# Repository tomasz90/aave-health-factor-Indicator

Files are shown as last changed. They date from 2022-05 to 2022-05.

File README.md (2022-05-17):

# Aave Health Factor Indicator


This project shows how healthy is your aave account. It has 16 built in leds as well as buzzer which signals when your hf drops below certain level.
It has a nice logo which shines in AAVE brand colors.

If you want to build this project you need:

* ESP8266 or ESP32
* 3x NEOPIXEL WS2812B modules, in my case I used two pcbs modules + few cm of flexible strips to light up logo
* one 5v buzzer
* few cables
* 3d prints based on attached stl files, one print needs transparent filament
* few insterts
* few screws

Pins needed to connect peripherals(leds, buzzer) are written in code - you can change them if you preffer, doesnt matter.
After programming controller, connect to access point created by ESP8266, configure your SSID and password.




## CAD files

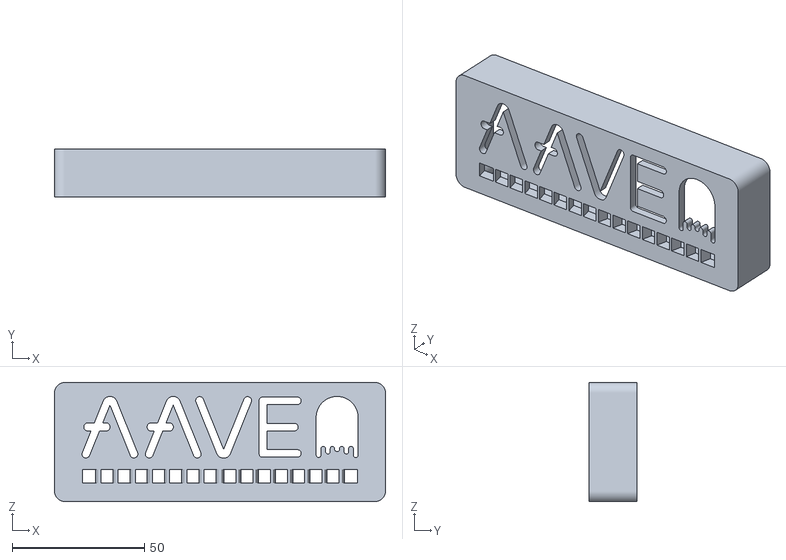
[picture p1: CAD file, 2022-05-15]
stl-3d/aave.stl
125.0 x 18.0 x 45.0

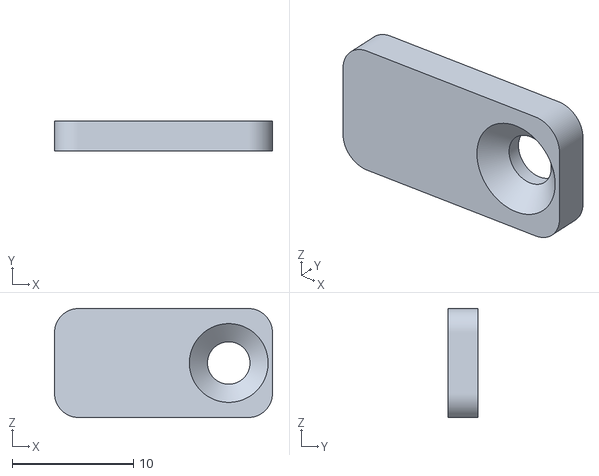
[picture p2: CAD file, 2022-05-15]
stl-3d/esp_holder.stl
18.0 x 2.50 x 9.00

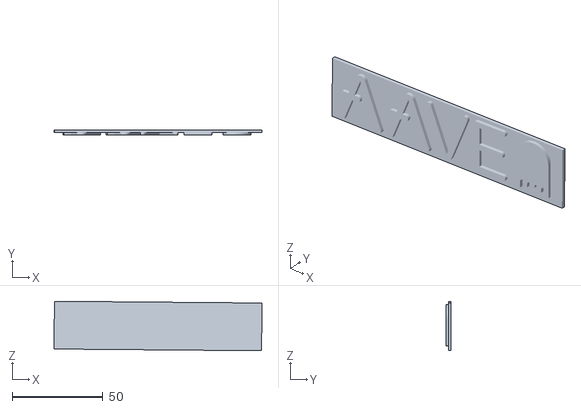
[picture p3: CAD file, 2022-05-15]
stl-3d/aave_window.stl
114.6 x 3.00 x 27.3

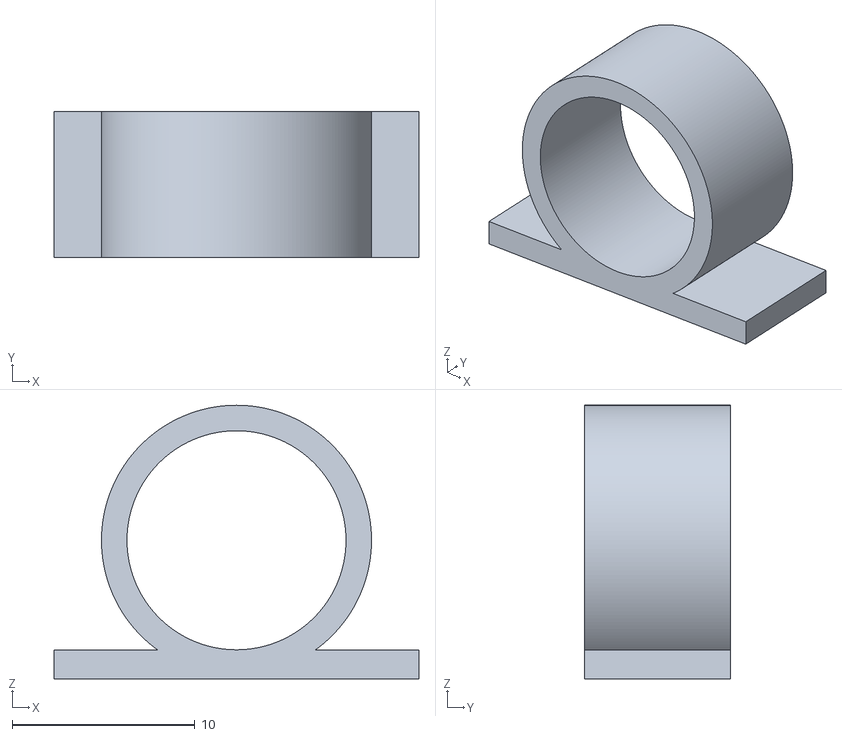
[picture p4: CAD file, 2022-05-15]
stl-3d/aave_speaker_holder.stl
20.0 x 8.00 x 15.0

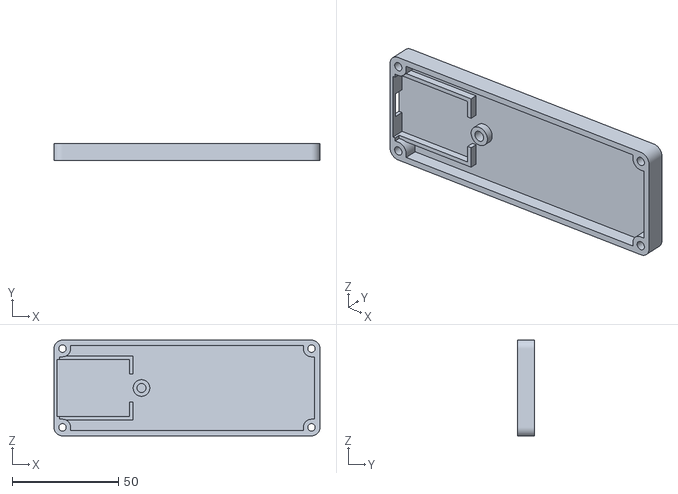
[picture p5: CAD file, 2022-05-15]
stl-3d/aave_cover.stl
125.0 x 8.00 x 45.0

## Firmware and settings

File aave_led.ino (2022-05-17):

#include <ESP8266WiFi.h>
#include <WiFiManager.h>
#include <Adafruit_NeoPixel.h>
#include <bitset>
#include <EEPROM.h>
#include <ESP8266HTTPClient.h>
#include <WiFiClientSecureBearSSL.h>

WiFiServer server(80);
WiFiManager manager;

String header;

struct Color {
  uint8 red;
  uint8 green;
  uint8 blue;
};

struct Settings {
  char chain[15];
  char address[42];
};

Settings settings;

String avaxRpc = "https://api.avax.network/ext/bc/C/rpc";
String polygonRpc = "https://polygon-rpc.com/";

String avaxPool = "0x4f01aed16d97e3ab5ab2b501154dc9bb0f1a5a2c";
String polygonPool = "0x8dFf5E27EA6b7AC08EbFdf9eB090F32ee9a30fcf";

String avaxPoolV3 = "0x794a61358D6845594F94dc1DB02A252b5b4814aD";
String polygonPoolV3 = "0x794a61358D6845594F94dc1DB02A252b5b4814aD";

unsigned long previousMillis = -25000;
const long interval = 30000;

static float hf;

void setup() {

  Serial.begin(9600);
  EEPROM.begin(sizeof(Settings));
  EEPROM.get(0, settings);

  setupAaveColors();
  setupIndicatorColors();

  manager.setConnectTimeout(10);
  manager.setConfigPortalTimeout(120);
  manager.autoConnect("ESP_AAVE", "password");

  connectToWifi();
  server.begin();
}

void loop() {
  displayAaveColors();

  WiFiClient client = server.available();
  displayWebPage(client);
  unsigned long currentMillis = millis();
  if (currentMillis - previousMillis >= interval) {
    previousMillis = currentMillis;
    updateHf();
  }
}

void updateHf() {
  connectToWifi(); // if disconnected
  if (strcmp(settings.chain, "AvalancheV3") == 0) {
    hf = getHf(avaxRpc, avaxPoolV3, settings.address);
  } else if (strcmp(settings.chain, "PolygonV3") == 0) {
    hf = getHf(polygonRpc, polygonPoolV3, settings.address);
  } else if (strcmp(settings.chain, "Avalanche") == 0) {
    hf = getHf(avaxRpc, avaxPool, settings.address);
  } else if (strcmp(settings.chain, "Polygon") == 0) {
    hf = getHf(polygonRpc, polygonPool, settings.address);
  }

  indicatorDisplay(hf);
  Serial.println(hf);
  Serial.println(settings.address);
  Serial.println(settings.chain);
}

void connectToWifi() {
  int _try = 0;
  long lastTry = millis();
  long _delay = 10000;
  while (WiFi.status() != WL_CONNECTED) {
    if (millis() - lastTry > _delay) {
      WiFi.reconnect();
      lastTry = millis();
      _try++;
    }
    if(_try > 10) {
      ESP.restart();
    }
    blinkBlue();
  }
}

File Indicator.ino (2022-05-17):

#define INDICATOR_PIN 13
#define INDICATOR_NUMPIXELS 16
#define BUZZER_PIN 14

Adafruit_NeoPixel indicator(INDICATOR_NUMPIXELS, INDICATOR_PIN, NEO_GRB + NEO_KHZ800);

uint32_t indicatorColor0 = indicator.Color(240, 20, 15);
uint32_t indicatorColor1 = indicator.Color(230, 30, 10);
uint32_t indicatorColor2 = indicator.Color(220, 40, 5);
uint32_t indicatorColor3 = indicator.Color(210, 50, 0);
uint32_t indicatorColor4 = indicator.Color(200, 60, 0);
uint32_t indicatorColor5 = indicator.Color(190, 70, 0);
uint32_t indicatorColor6 = indicator.Color(180, 80, 0);
uint32_t indicatorColor7 = indicator.Color(170, 90, 0);
uint32_t indicatorColor8 = indicator.Color(160, 100, 0);
uint32_t indicatorColor9 = indicator.Color(150, 110, 0);
uint32_t indicatorColor10 = indicator.Color(140, 120, 0);
uint32_t indicatorColor11 = indicator.Color(130, 130, 0);
uint32_t indicatorColor12 = indicator.Color(120, 140, 0);
uint32_t indicatorColor13 = indicator.Color(110, 150, 5);
uint32_t indicatorColor14 = indicator.Color(100, 160, 10);
uint32_t indicatorColor15 = indicator.Color(90, 170, 15);
uint32_t indicatorColorX = indicator.Color(0, 0, 0);

uint32_t indicator_colors[16] = {
  indicatorColor0, indicatorColor1, indicatorColor2, indicatorColor3,
  indicatorColor4, indicatorColor5, indicatorColor6, indicatorColor7,
  indicatorColor8, indicatorColor9, indicatorColor10, indicatorColor11,
  indicatorColor12, indicatorColor13, indicatorColor14, indicatorColor15
};

void setupIndicatorColors() {
  indicator.begin();
  indicator.clear();
  indicator.setBrightness(15);
  pinMode(BUZZER_PIN, OUTPUT);
}

void indicatorDisplay(float hf) {

  int pixels = (hf - 1.4) / 0.1;

  if (hf == 0.0) {
    blinkOrange();
    return;
  }

  if (hf > 5) {
    setAllPixels(indicatorColor15);
    return;
  }

  if (pixels < 0) {
    blinkRed();
    return;
  }

  int firstBlack = 0;
  while (indicator.getPixelColor(firstBlack) != 0) {
    firstBlack++;
  }

  if (pixels > INDICATOR_NUMPIXELS - 1) {
    pixels = INDICATOR_NUMPIXELS - 1;
  }

  Serial.println(pixels);
  Serial.println(firstBlack);

  if (firstBlack - 1 <= pixels) {
    for (int i = 0; i <= pixels; i++) {
      indicator.setPixelColor(i, indicator_colors[i]);
      indicator.show();
      delay(200);
    }
  } else {
    for (int i = firstBlack; i > pixels; i--) {
      indicator.setPixelColor(i, indicatorColorX);
      indicator.show();
      delay(200);
    }
  }
}

void blinkOrange() {
  for (int i = 0; i < 10; i++) {
    setAllPixels(indicatorColorX);
    delay(300);
    setAllPixels(indicatorColor7);
    delay(300);
  }
}

void blinkRed() {
  for (int i = 0; i < 10; i++) {
    tone(BUZZER_PIN, 1000);
    setAllPixels(indicatorColor0);
    delay(300);
    noTone(BUZZER_PIN);
    setAllPixels(indicatorColorX);
    delay(300);
    setAllPixels(indicatorColor0);
  }
}

void blinkBlue() {
  setBlue();
  delay(250);
  setBlank();
  delay(250);
}

void setAllPixels(int color) {
  for (int i = 0; i < INDICATOR_NUMPIXELS; i++) {
    indicator.setPixelColor(i, color);
  }
  indicator.show();
}

void setBlue() {
  setAllPixels(indicator.Color(40, 90, 150));
}

void setBlank() {
  setAllPixels(indicatorColorX);
}

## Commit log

2022-03-24 almost done, led needs rework
2022-03-24 fixed problem with submitting blank input
    [Indicator.ino]
2022-03-25 added orange color, when problem with requests
    [Indicator.ino]
2022-03-25 fixed leds
2022-03-25 fixed leds2
2022-05-15 added stl
    [aave.stl, aave_cover.stl, aave_speaker_holder.stl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]
2022-05-17 tries 5 power off, working fine
